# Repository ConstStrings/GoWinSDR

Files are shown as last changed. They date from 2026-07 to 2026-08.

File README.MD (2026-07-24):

# GoWinSDRv2 即将发布，正在开发中

**主要改进及进度如下**

| 名称 | 功能或改进 | 开发进度 |
| --- | --- | --- |
| SDR核心底板 | 优化射频布局，优化以太网布局，增强稳定性；优化接口排布；预留烧录器接口；增加40pin拓展接口；采用温度补偿晶振；添加状态指示灯 | 硬件打板完成，正在调试 |
| 板载烧录器  | 可直接固定在SDR核心底板上，一线烧录 | 开发完成 |
| SDR扩展底板 | 集成DAC模拟输出，音频输出及音频功放，GPS时钟校准，串口屏 | 正在设计PCB |
| FPGA程序 | 修复已知bug | 正在开发 |

**目前v2版本尚未开发完毕，正常情况下请勿使用该版本！！！该页面仅供预览，请使用v1版本！！！**

# GoWinSDR

**最后由ConstString于2026-03-16编辑**

**Click to Read English Version：https://github.com/ConstStrings/GoWinSDR/blob/master/README_EN.MD**

## 工程简介

**本项目基于高云 GW5AT-LV60 FPGA与ADI AD9363/AD9361射频收发器，构建了一套灵活可重构的软件无线电（SDR）系统。通过软硬件协同设计，将高速基带处理部署于FPGA，将交互业务部署于Python上位机，通过千兆以太网交互，实现了QPSK等多种实时通信与动态参数配置**

系统可通过千兆以太网或 USB2.0 (开发中)接口连接 PC 端，配套开发的图形用户界面（GUI上位机）能够直观展示通信参数、数据传输状态等信息，支持用户实时配置系统参数、监控传输过程，大幅提升了人机交互体验。经实际测试，该 SDR 无线通信系统可实现两台设备间的真实无线通信，数据传输速率高达 4Mbps

本工程所使用的FPGA只有PL端，因此将AD936X射频芯片的初始化部分代码移植至STM32平台，经测试运行稳定，使用较为方便。除初始化外的所有逻辑均在FPGA上用Verilog实现

相比Xilinx ZYNQ平台上众多的软件无线电开源项目，本项目没有使用异构FPGA，核心逻辑均使用Verilog实现，数据传输路径更加清晰，操作逻辑更加直观和接近底层，便于无线电爱好者/通信工程师/学生等人群更深入的了解软件无线电基本原理，或作为基本平台进行编码等内容的二次开发



## 工程结构

```

GoWinSDR/
├── FPGA/
│   ├── SDR_Final_CMOS/ # 完整版FPGA项目，基于SDR Base底板，实现所有功能
│   ├── SDR_TANG_CMOS/ # AD9363测试项目，基于AD9363_Debug测试板和Sipeed Tang Mega开发板，只能收发单音信号
│   └── Submodule/ # 用于存放测试时使用的子模块，非开发人员请勿使用
├── Firmware/
│   └── GoWinSDR_STM32/ # 初始化AD9363的STM32代码，移植自Xilinx，使用HAL库开发
├── Hardware/
│   ├── Gerber/ # PCB制版文件
│   ├── ProPrj_AD9363_Debug/ # 嘉立创EDA工程，AD9363功能测试板
│   └── ProPrj_GoWinSDR_SMT/ # 嘉立创EDA工程，项目完整PCB
├── Image/  # 存放文档图片
├── Matlab/  # 用于生成滤波器系数
├── Software/ # 基于PyQt的上位机
└── README.MD
```

## 系统框图



## 快速使用

1. **打样工程ProPrj_GoWinSDR_SMT并焊接，测试各部分电源正常**
2. **打开工程GoWinSDR_STM32，通过板载SWD烧录STM32程序**
3. **打开工程SDR_Final_CMOS，将程序下载/固化到FPGA**
4. **使用Pycharm或其他软件运行上位机，检测参数能否配置，能否收发信号**
5. **若发现某一部分工作异常，可以通过串口和高云FPGA内置逻辑分析仪分析错误**

## 核心代码功能介绍
**核心代码位于目录\FPGA\SDR_Final_CMOS\src下**

### 顶层模块
#### `top.v`
> 顶层模块，负责连接各子模块
---
### AD936X 接口
#### `ad9363_dev_cmos.v`
> AD9363 CMOS接口驱动模块。使用IDDR原语从12位并行总线同时采集I/Q两路ADC数据，使用ODDR原语将I/Q两路DAC数据交替输出至发送总线，实现AD9363芯片的收发时序控制。
---
### 以太网
#### `eth_transceiver.v`
> 以太网收发器顶层模块。通过RGMII接口驱动千兆PHY芯片，内部集成125MHz PLL、UDP/IP协议栈，对外提供简洁的用户数据收发接口，支持ARP应答与UDP数据包的封装解析。
#### `eth_frame_gene.v`
> 射频数据帧封装模块（`rf_data_processor`）。将以太网接收到的用户数据加上自定义帧头（`0xEB90CAD3`）和帧尾（`0x55AA5C4B`），通过跨时钟域FIFO送至射频发送侧，用于无线链路的帧同步。
#### `eth_pack.v`
> 射频数据解帧模块（`rf_data_framer`）。从射频解调比特流中搜索帧头，提取有效载荷，通过跨时钟域FIFO送至以太网发送侧，同时支持IQ互换帧头识别与超时帧错误检测。
#### `arp_responder.v`
> ARP响应模块。监听以太网输入数据流，识别ARP请求包并提取发送方MAC/IP，自动构造并回复ARP应答帧，使PC能够正确解析FPGA的MAC地址。
#### `crc.v`
> CRC校验模块，用于以太网帧数据的完整性校验。
---
### 调制解调
#### `qpsk_demod.v`
> QPSK解调顶层模块。集成采样时钟生成、DDS载波生成、混频下变频、低通滤波、Costas环载波同步、Gardner定时同步及差分解码等子模块，完成从中频采样数据到基带比特流的完整解调链路。
#### `costas.v`
> Costas环载波恢复模块。利用片内DDS生成本地载波，对输入I/Q信号进行正交混频，经鉴相器与环路滤波器闭环控制DDS相位，消除接收信号的载波频偏与相偏。
#### `costas_flt_new.v`
> 改进型Costas环路滤波器（`costas_loop_filter_new`）。实现带积分饱和保护的PI（比例-积分）控制器，可配置KP/KI增益参数，将鉴相器误差转换为DDS相位调整量，加快环路锁定速度并提升稳定性。
#### `costas_loop_filter.v`
> Costas环一阶IIR环路滤波器。实现系统函数 `H(z) = c1 + c2·z⁻¹/(1−z⁻¹)` 的差分方程，采用双增益系数组自适应切换策略（前期大系数快速牵引，后期小系数稳定跟踪），输出24位相位控制字。
#### `phase_detector.v`
> QPSK载波同步鉴相器。依据I/Q两路低通滤波后信号的符号位，采用判决引导法计算相位误差：`error = Q·sign(I) − I·sign(Q)`，输出58位有符号相位误差供环路滤波器使用。
#### `gardner_sync.v`
> Gardner定时同步顶层模块。串联内插滤波器、Gardner TED误差检测器与NCO，构成完整的符号定时恢复闭环，输出最佳抽样时刻的I/Q判决数据及同步标志。
#### `gardner_ted.v`
> Gardner定时误差检测器（TED）。利用Gardner算法 `e(k) = I(k−1)·[I(k)−I(k−2)]` 计算符号定时误差，经一阶IIR环路滤波后输出16位误差控制字，同时在最佳判决时刻输出I/Q硬判决数据。
#### `nco.v`
> 数控振荡器（NCO）模块。接收环路滤波器输出的频率控制字`w(n)`，对内部寄存器η递减累加，当η下溢（出现负值）时产生strobe溢出信号，同时输出用于内插滤波器的小数间隔μk，实现符号定时控制。
#### `interpolate_filter.v`
> Farrow结构内插滤波器。依据NCO输出的小数间隔μk，对I/Q输入样值序列进行分段多项式内插（`y(k) = f1·μk² + f2·μk + f3`），在任意相位点重建信号，实现非整数倍采样率转换。
---
### 射频收发
#### `rf_rxt.v`
> 射频收发处理顶层模块。接收侧串联Costas环、Gardner定时同步与差分解码，完成QPSK解调输出比特流；发送侧对输入字节数据进行差分编码与QPSK星座映射，驱动DAC输出I/Q基带信号。
#### `rf_diff_encode.v`
> QPSK差分编码模块（`qpsk_differential_encoder`）。将当前2位输入数据与上一时刻I/Q状态进行异或运算，实现差分相移编码（DQPSK），消除解调端的相位模糊问题。
#### `rf_diff_decode.v`
> QPSK差分解码模块（`qpsk_differential_decoder`）。将当前I/Q判决位与前一符号进行异或，恢复原始2位数据，与差分编码端对应，实现相位模糊的透明消除。
---
### 其他
#### `calibration.v`
> 信号校准模块。对ADC输入数据进行平方运算，经FIR低通滤波提取信号包络，再由正弦波频率计测量当前频率，最终通过`data_sender_24bit`将24位校准频率数据输出至外部（STM32），用于系统标定。
#### `com_fpga.v`
> FPGA与MCU通信模块（`data_sender_24bit`）。将128分频后的低速时钟作为数据时钟，在STM32请求信号触发下，按状态机逐字节串行输出24位数据，实现FPGA向STM32的同步并行数据传输。
#### `led_control.v`
> 433MHz OOK解调模块（`demod_433`）。对ADC输入的I/Q信号计算瞬时功率（I²+Q²），经64次滑动平均滤波后与功率阈值比较，输出OOK解调数据位，可用于LED状态指示或低速遥控信号接收。
---
### 约束文件
#### `SDR_Test.cst`
> 管脚约束文件
#### `timeconstrain.sdc`
> 时序约束文件
#### `SDR_Test.rao`
> 逻辑分析仪配置文件

## ARM端程序使用方法

**核心代码位于目录\Firmware\GoWinSDR_STM32\Hardware下**

主程序已经实现串口命令读取和配置参数，故可以不用修改代码，直接烧录。需要根据实际引脚修改文件`\Firmware\GoWinSDR_STM32\\Hardware\api\softspi.h`内的SPI相关引脚。

如果想进行更加细致的配置，可修改main.c内的初始化结构体 `AD9361_InitParam default_init_param`，参数具体含义已在注释中

初始化时会通过串口打印初始化日志，初始化成功后打印当前状态：

```
采样频率:
  RX: 61440000 Hz (61.44 MSPS)
  TX: 61440000 Hz (61.44 MSPS)
ad9361_rfpll_int_recalc_rate: Parent Rate 80000000 Hz
ad9361_rfpll_int_recalc_rate: Parent Rate 80000000 Hz

LO频率:
  RX: 2400000000 Hz (2.400 GHz)
  TX: 2400000000 Hz (2.400 GHz)
ad9361_set_tx_atten : attenuation 0 mdB tx1=1 tx2=0
Rx gain can be set in MGC mode only
ad9361_rf_port_setup : INPUT_SELECT 0x3

=== Final Status ===
ENSM (0x017): 0x1A (TX_ON=1)
TX Ctrl (0x002): 0x58
PLL Lock (0x247): 0x02 (TX_PLL=1)
```

支持使用的命令如下，使用串口即可配置，想要查看和修改指令逻辑可以查看\Firmware\GoWinSDR_STM32\\Hardware\ad9361\command.c：

```
help?  - Displays all available commands.
register?  - Gets the specified register value.
tx_lo_freq?  - Gets current TX LO frequency [MHz].
tx_lo_freq=  - Sets the TX LO frequency [MHz].
tx_samp_freq?  - Gets current TX sampling frequency [Hz].
tx_samp_freq=  - Sets the TX sampling frequency [Hz].
tx_rf_bandwidth?  - Gets current TX RF bandwidth [Hz].
tx_rf_bandwidth=  - Sets the TX RF bandwidth [Hz].
tx1_attenuation?  - Gets current TX1 attenuation [mdB].
tx1_attenuation=  - Sets the TX1 attenuation [mdB].
tx2_attenuation?  - Gets current TX2 attenuation [mdB].
tx2_attenuation=  - Sets the TX2 attenuation [mdB].
tx_fir_en?  - Gets current TX FIR state.
tx_fir_en=  - Sets the TX FIR state.
rx_lo_freq?  - Gets current RX LO frequency [MHz].
rx_lo_freq=  - Sets the RX LO frequency [MHz].
rx_samp_freq?  - Gets current RX sampling frequency [Hz].
rx_samp_freq=  - Sets the RX sampling frequency [Hz].
rx_rf_bandwidth?  - Gets current RX RF bandwidth [Hz].
rx_rf_bandwidth=  - Sets the RX RF bandwidth [Hz].
rx1_gc_mode?  - Gets current RX1 GC mode.
rx1_gc_mode=  - Sets the RX1 GC mode.
rx2_gc_mode?  - Gets current RX2 GC mode.
rx2_gc_mode=  - Sets the RX2 GC mode.
rx1_rf_gain?  - Gets current RX1 RF gain.
rx1_rf_gain=  - Sets the RX1 RF gain.
rx2_rf_gain?  - Gets current RX2 RF gain.
rx2_rf_gain=  - Sets the RX2 RF gain.
rx_fir_en?  - Gets current RX FIR state.
rx_fir_en=  - Sets the RX FIR state.
dds_tx1_tone1_freq?  - Gets current DDS TX1 Tone 1 frequency [Hz].
dds_tx1_tone1_freq=  - Sets the DDS TX1 Tone 1 frequency [Hz].
dds_tx1_tone2_freq?  - Gets current DDS TX1 Tone 2 frequency [Hz].
dds_tx1_tone2_freq=  - Sets the DDS TX1 Tone 2 frequency [Hz].
dds_tx1_tone1_phase?  - Gets current DDS TX1 Tone 1 phase [degrees].
dds_tx1_tone1_phase=  - Sets the DDS TX1 Tone 1 phase [degrees].
dds_tx1_tone2_phase?  - Gets current DDS TX1 Tone 2 phase [degrees].
dds_tx1_tone2_phase=  - Sets the DDS TX1 Tone 2 phase [degrees].
dds_tx1_tone1_scale?  - Gets current DDS TX1 Tone 1 scale.
dds_tx1_tone1_scale=  - Sets the DDS TX1 Tone 1 scale.
dds_tx1_tone2_scale?  - Gets current DDS TX1 Tone 2 scale.
dds_tx1_tone2_scale=  - Sets the DDS TX1 Tone 2 scale.
dds_tx2_tone1_freq?  - Gets current DDS TX2 Tone 1 frequency [Hz].
dds_tx2_tone1_freq=  - Sets the DDS TX2 Tone 1 frequency [Hz].
dds_tx2_tone2_freq?  - Gets current DDS TX2 Tone 2 frequency [Hz].
dds_tx2_tone2_freq=  - Sets the DDS TX2 Tone 2 frequency [Hz].
dds_tx2_tone1_phase?  - Gets current DDS TX2 Tone 1 phase [degrees].
dds_tx2_tone1_phase=  - Sets the DDS TX2 Tone 1 phase [degrees].
dds_tx2_tone2_phase?  - Gets current DDS TX2 Tone 2 phase [degrees].
dds_tx2_tone2_phase=  - Sets the DDS TX2 Tone 2 phase [degrees].
dds_tx2_tone1_scale?  - Gets current DDS TX2 Tone 1 scale.
dds_tx2_tone1_scale=  - Sets the DDS TX2 Tone 1 scale.
dds_tx2_tone2_scale?  - Gets current DDS TX2 Tone 2 scale.
dds_tx2_tone2_scale=  - Sets the DDS TX2 Tone 2 scale.
calibration?  - Get Lo Freq diff.
calibration=  - Calibrate Lo Freq diff.
rx_lo_up=  - Increase RX LO frequency.
rx_lo_down=  - Decrease RX LO frequency.
query_led_state?  - Decrease RX LO frequency.
query_led_state=  - Decrease RX LO frequency.

```

## 上位机功能介绍

上位机基于 **Python + PyQt6** 开发，采用多线程架构，通过串口与以太网双通道与 FPGA 通信，提供图形化的参数配置、数据收发与实时监控功能。

---

### 启动方法

安装好Python开发环境后，在PyCharm等软件内运行main.py

### 整体架构

主窗口 (`main_window.py`) 采用左右分栏布局：左侧为配置区，右侧为多选项卡功能区。后台运行多个独立的 QThread 工作线程，分别负责串口通信、UDP 网络收发、音频流采集/播放和摄像头采集，所有线程间通过 Qt 信号槽机制进行线程安全的数据传递。

---

### 串口通信

`serial_worker.py` 实现了串口工作线程，支持可用端口枚举、可配置波特率（最高 921600bps）的串口连接/断开，以及全双工的数据收发。接收端对数据流进行逐行解析：格式为 `key=value` 的响应被识别为参数回调并转发至参数面板，其余内容作为日志显示。

`config_widget.py` 提供串口配置 UI，包含端口刷新、波特率选择及连接状态管理。

---

### 以太网通信（UDP）

`ethernet_worker.py` 实现了基于 UDP 的可靠/不可靠双模式传输协议：

- **文本命令**：采用停等协议（Stop-and-Wait），支持最多 128 次重传。
- **文件传输**：先用停等协议发送文件头（含文件名与大小），再用 **SR（Selective Repeat）滑动窗口协议**（窗口大小为 4）发送文件数据，实现乱序重传；全程携带 CRC32 校验。
- **实时视频流**：采用自定义分包协议（帧头含帧ID、分片序号、总分片数），允许丢包，每帧拆分为最大 1024 字节的分片后以不可靠方式发送，接收端按帧ID进行分片重组。
- **实时音频流**：以不可靠方式直接发送 PCM 音频块，保证低延迟实时性。

`ethernet_widget.py` 提供 UDP 配置 UI，含 FPGA 目标地址（IP/端口）和本地监听地址配置，以及开始/停止监听按钮。

---

### AD9363 参数配置

`params_widget.py` 提供 AD9363 射频芯片的参数配置面板，分 TX（发射）和 RX（接收）两个选项卡，涵盖本振频率、采样率、射频带宽、增益控制、FIR 使能及 DDS 音调频率等参数的读取与设置。每个参数条目包含输入框和 Set 按钮，点击后通过串口发送 `key=value` 格式命令。支持"手动查询所有参数"一键刷新，以及在连接后自动批量查询所有 GET 命令（`ad9363_config.py` 中定义）。

---

### 文件、文本及录音

`text_audio_widget.py` 支持通过串口发送文本消息，以及触发音频录制/停止。

`file_send_widget.py` 实现文件发送 UI，包含文件浏览、文件信息预览（文件名、大小、类型、路径），以及带实时进度条、传输速率（Mbps）和预计剩余时间的传输状态显示。

`file_receive_widget.py` 实现文件接收 UI，支持启用/禁用文件接收，显示带进度条和速率的实时接收状态，已接收文件列入表格并可选择保存到本地。

---

### 实时语音传输

`realtime_audio_widget.py` 提供实时双向语音传输界面，发射侧支持枚举系统音频输入设备（包括 WASAPI 内录），选择音源后启动麦克风采集并通过 UDP 实时发送；接收侧将网络接收的 PCM 数据送入音频输出队列实时播放。两侧均内嵌波形图实时显示音频波形。

`audio_stream_worker.py` 基于 sounddevice 库实现：`AudioInputWorker` 以回调方式从指定设备连续采集 44100Hz/单声道/float32 音频块；`AudioOutputWorker` 通过队列缓冲驱动扬声器输出，缓冲不足时静音以减少噪声。

---

### 实时视频传输

`realtime_video_widget.py` 提供实时双向视频界面，发射侧开启本地摄像头并实时预览，同时将视频帧编码为 WebP 格式通过 UDP 发送；接收侧将网络视频帧解码后实时渲染。

`camera_worker.py` 基于 OpenCV 实现摄像头采集，在独立内部线程中以设定的限速循环抓帧，水平翻转后分别发出 QImage（供本地预览）和 WebP 字节流（供网络发送）两路信号。

---

### 网络视频监控

`video_widget.py` 提供独立的 UDP 视频监控选项卡，仅用于接收和显示来自 FPGA/网络的视频流，支持视频标签自动缩放。

---

### 无线物联网控制

`iot_widget.py` 实现一个简单的 IoT 设备状态监控演示页面。启动监控后自动设置 RX 本振频率至 434MHz，并以 500ms 为周期轮询 `query_led_state?` 指令；根据串口返回的状态（"1"/"0"）驱动自绘灯泡控件亮起或熄灭，模拟 433MHz 无线遥控设备的状态可视化。

---

### 波形显示

`waveform_widget.py` 是一个基于 QPainter 和 NumPy 的自定义音频波形控件，采用离屏 Pixmap 双缓冲渲染，支持可调增益放大（默认 5 倍）与幅度裁剪，自适应控件宽度对波形数据进行采样/插值显示。

---

## PCB相关事项（重要，仔细阅读）

1. 由于包含射频和高速信号，进行PCB打样时**需要进行阻抗管控**！！！，使用嘉立创进行打样，层压选择**JLC06161H-3313**，阻抗管控+/-20%即可

2. 焊接时如果没有把握，**请务必先焊接电源部分，确定电源输出电压正常后再焊接其他部分**，防止烧毁芯片

3. 上电前请**确定各路电源是否对地短路**，即使是SMT也是有可能短路的

4. PCB已经经过多版本迭代，理论上不存在重大问题，请先确定焊接是否到位

5. **重要！！：核心板上可以通过VDDIO设置bank电压，但如果和底板同时提供VDDIO会造成冲突，因此需要在插入核心板前将核心板上的IO供电移除，具体方法如下**

   查看核心板原理图，发现VDDIO供电经过磁珠连接到3.3v电源，我们只需要断开我们所使用Bank对应的磁珠，**FB14,FB15,FB16**

   

	这三个磁珠在核心板背面对应的位置如下，需要用烙铁将这三个磁珠去除即可

        

## 测试结果

### 文件传输测试



### 逻辑分析仪（截图时QPSK正在修复问题，暂时采用BPSK）

#### 完整系统时序图



#### AD9363单独测试

测试在2.4GHz频段下进行BPSK通信，最上面的四行分别是接收IQ路和发射IQ路，波形较为完整，没有明显的失真





测试在2.4GHz情况下，**不插天线**，观察正弦单音信号的失真情况



### 上位机视频传输

使用上位机的视频传输功能，可以使用在参数设置页面自定义的频段传输实时视频流。使用自收自发的方式（可以板间传输）进行测试，视频源为笔记本摄像头，左侧画面为摄像头捕获画面，右侧为从射频信号中解码所得的画面。得益于FPGA的强实时性，几乎感受不到延迟



### 以太网数据流

通过WireShark软件可以查看在以太网中传输的数据流，传输文件过程中的以太网数据流如下，分为数据帧和ACK帧



### 频谱情况（早期测试结果）



## 成品展示









## 声明

- 本工程的Costas环与Gardner环部分参考开源工程：https://github.com/lauchinyuan/FPGA_QPSK-modem 非常感谢大佬的开源
- 本工程的以太网收发器部分参考自Sipeed例程：https://github.com/sipeed/TangMega-138K-example，本工程初始验证版也是基于Sipeed出品的TangMega-138K开发板

## 写在最后

**这个工程耗费我个人及我们团队相当大的精力，尽管AD936X是一款资料较多的成熟芯片，但现有项目基本是建立在ZYNQ系列上的，代码耦合程度较高，不方便学习。调试软件和硬件的过程非常痛苦，但好在最后成功将整个系统基本搭建成功，并在2025年的嵌赛FPGA赛道决赛中获得奖项。由于各种各样的主客观原因，一部分设计目标尚未完成，ARP请求未实现需手动添加（截止2026-3-10），QPSK会出现bug（截止2026-3-10）,  Gardner环在高码率会失锁（截止2026-3-10），在繁忙的学业之余，我会尽力去完善这个项目，也希望大家谅解**

如果有任何问题或想要交流，可以通过邮件联系我：
3207235590@qq.com
conststrings@gmail.com

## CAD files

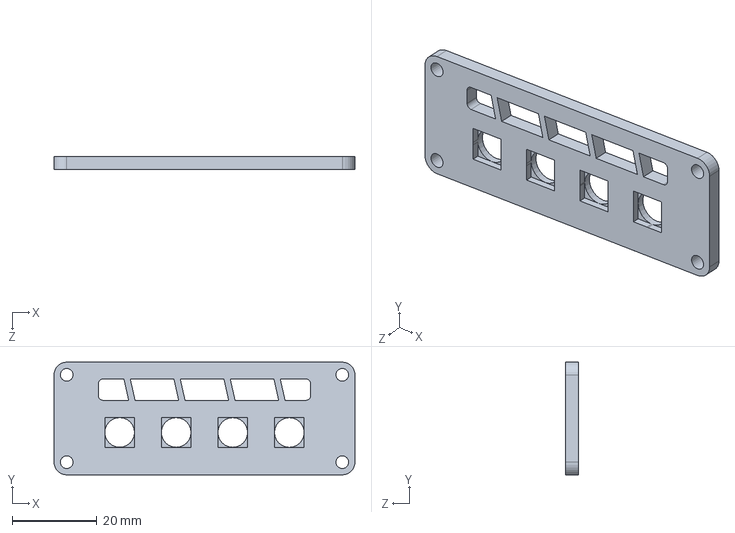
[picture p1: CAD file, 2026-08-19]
Struct/left.SLDPRT
71.0 x 26.6 x 3.00 mm

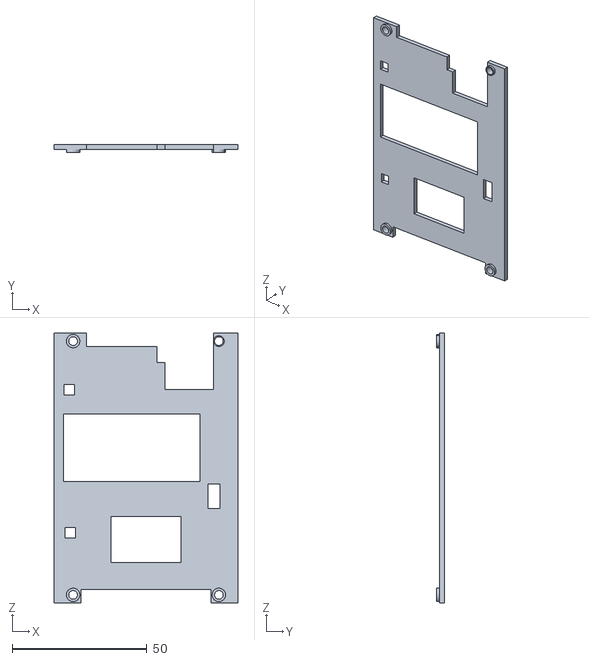
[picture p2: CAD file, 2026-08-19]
Struct/base3.STL
68.0 x 2.80 x 100.0

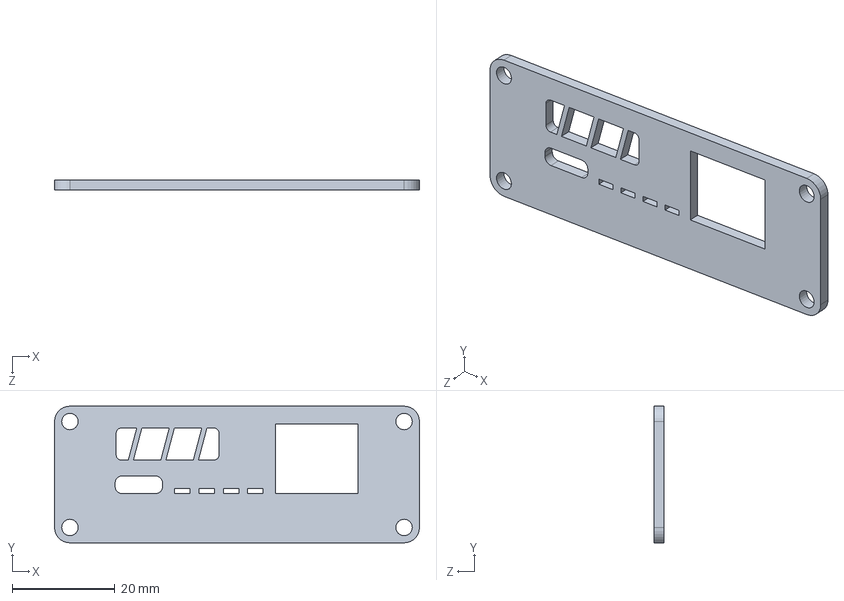
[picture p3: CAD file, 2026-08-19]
Struct/right.SLDPRT
71.0 x 26.6 x 2.00 mm

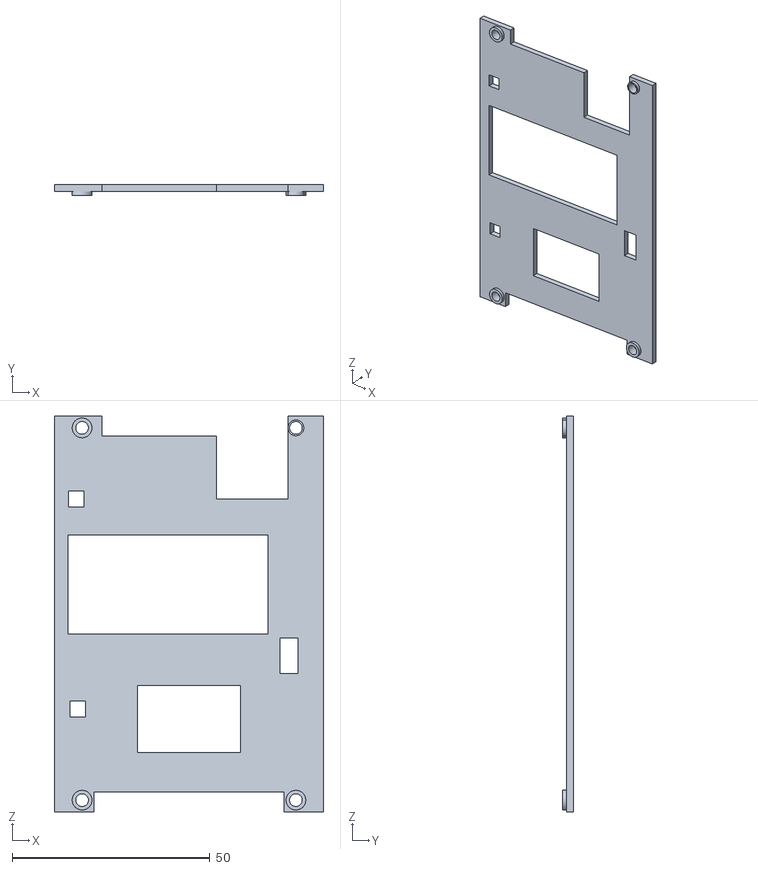
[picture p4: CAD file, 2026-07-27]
Struct/base2.STL
68.0 x 2.80 x 100.0

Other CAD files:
Struct/base.SLDPRT
Struct/base.STL
Struct/left.STL
Struct/right.STL

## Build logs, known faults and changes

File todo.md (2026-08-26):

1. 查看原始波形质量（正弦收发）
2. costas有问题
3. 信道编码
4. 连续数据流控，DDR buffer

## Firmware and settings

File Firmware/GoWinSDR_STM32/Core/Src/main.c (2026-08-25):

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
/* Includes ------------------------------------------------------------------*/
#include "main.h"
#include "adc.h"
#include "spi.h"
#include "tim.h"
#include "usart.h"
#include "gpio.h"

/* USER CODE BEGIN Includes */
#include "com_debug.h"
#include "config.h"
#include "ad9361_api.h"
#include "parameters.h"
#include "platform.h"
#include "command.h"
#include "console.h"
#include "adc_core.h"
#include "dac_core.h"
#include "softspi.h"
/* USER CODE END Includes */


void SystemClock_Config(void);
/* USER CODE BEGIN 0 */
#ifdef CONSOLE_COMMANDS
extern command	  	cmd_list[];
extern char			cmd_no;
extern cmd_function	cmd_functions[11];
unsigned char		cmd				 =  0;
double				param[5]		 = {0, 0, 0, 0, 0};
char				param_no		 =  0;
int					cmd_type		 = -1;
char				invalid_cmd		 =  0;
char				received_cmd[30] = {0, 0, 0, 0, 0, 0, 0, 0, 0, 0,
										0, 0, 0, 0, 0, 0, 0, 0, 0, 0,
										0, 0, 0, 0, 0, 0, 0, 0, 0, 0};
#endif

AD9361_InitParam default_init_param = {
	/* Device selection */
	ID_AD9361,	// dev_sel
	/* Identification number */
	0,		//id_no
	/* Reference Clock */
	40000000UL,	//reference_clk_rate
	/* Base Configuration */
	0,		//two_rx_two_tx_mode_enable *** adi,2rx-2tx-mode-enable
	1,		//one_rx_one_tx_mode_use_rx_num *** adi,1rx-1tx-mode-use-rx-num
	1,		//one_rx_one_tx_mode_use_tx_num *** adi,1rx-1tx-mode-use-tx-num
	1,		//frequency_division_duplex_mode_enable *** adi,frequency-division-duplex-mode-enable
	0,		//frequency_division_duplex_independent_mode_enable *** adi,frequency-division-duplex-independent-mode-enable
	0,		//tdd_use_dual_synth_mode_enable *** adi,tdd-use-dual-synth-mode-enable
	0,		//tdd_skip_vco_cal_enable *** adi,tdd-skip-vco-cal-enable
	0,		//tx_fastlock_delay_ns *** adi,tx-fastlock-delay-ns
	0,		//rx_fastlock_delay_ns *** adi,rx-fastlock-delay-ns
	0,		//rx_fastlock_pincontrol_enable *** adi,rx-fastlock-pincontrol-enable
	0,		//tx_fastlock_pincontrol_enable *** adi,tx-fastlock-pincontrol-enable
	0,		//external_rx_lo_enable *** adi,external-rx-lo-enable
	0,		//external_tx_lo_enable *** adi,external-tx-lo-enable
	5,		//dc_offset_tracking_update_event_mask *** adi,dc-offset-tracking-update-event-mask
	6,		//dc_offset_attenuation_high_range *** adi,dc-offset-attenuation-high-range
	5,		//dc_offset_attenuation_low_range *** adi,dc-offset-attenuation-low-range
	0x28,	//dc_offset_count_high_range *** adi,dc-offset-count-high-range
	0x32,	//dc_offset_count_low_range *** adi,dc-offset-count-low-range
	0,		//split_gain_table_mode_enable *** adi,split-gain-table-mode-enable
	MAX_SYNTH_FREF,	//trx_synthesizer_target_fref_overwrite_hz *** adi,trx-synthesizer-target-fref-overwrite-hz
	0,		// qec_tracking_slow_mode_enable *** adi,qec-tracking-slow-mode-enable
	/* ENSM Control */
	0,		//ensm_enable_pin_pulse_mode_enable *** adi,ensm-enable-pin-pulse-mode-enable
	0,		//ensm_enable_txnrx_control_enable *** adi,ensm-enable-txnrx-control-enable
	/* LO Control */
	2400000000UL,	//rx_synthesizer_frequency_hz *** adi,rx-synthesizer-frequency-hz
	2400000000UL,	//tx_synthesizer_frequency_hz *** adi,tx-synthesizer-frequency-hz
	/* Rate & BW Control */
	{983040000, 245760000, 122880000, 61440000, 30720000, 30720000},//uint32_t	rx_path_clock_frequencies[6] *** adi,rx-path-clock-frequencies
	{983040000, 245760000, 122880000, 61440000, 30720000, 30720000},//uint32_t	tx_path_clock_frequencies[6] *** adi,tx-path-clock-frequencies
	18000000,//rf_rx_bandwidth_hz *** adi,rf-rx-bandwidth-hz
	18000000,//rf_tx_bandwidth_hz *** adi,rf-tx-bandwidth-hz
	/* RF Port Control */
	0,		//rx_rf_port_input_select *** adi,rx-rf-port-input-select
	0,		//tx_rf_port_input_select *** adi,tx-rf-port-input-select
	/* TX Attenuation Control */
	0,	//tx_attenuation_mdB *** adi,tx-attenuation-mdB
	0,		//update_tx_gain_in_alert_enable *** adi,update-tx-gain-in-alert-enable
	/* Reference Clock Control */
	0,		//xo_disable_use_ext_refclk_enable *** adi,xo-disable-use-ext-refclk-enable
	{8, 5920},	//dcxo_coarse_and_fine_tune[2] *** adi,dcxo-coarse-and-fine-tune
	CLKOUT_DISABLE,	//clk_output_mode_select *** adi,clk-output-mode-select
	/* Gain Control */
	RF_GAIN_SLOWATTACK_AGC,		//gc_rx1_mode *** adi,gc-rx1-mode
	RF_GAIN_SLOWATTACK_AGC,		//gc_rx2_mode *** adi,gc-rx2-mode
	58,		//gc_adc_large_overload_thresh *** adi,gc-adc-large-overload-thresh
	4,		//gc_adc_ovr_sample_size *** adi,gc-adc-ovr-sample-size
	47,		//gc_adc_small_overload_thresh *** adi,gc-adc-small-overload-thresh
	8192,	//gc_dec_pow_measurement_duration *** adi,gc-dec-pow-measurement-duration
	0,		//gc_dig_gain_enable *** adi,gc-dig-gain-enable
	800,	//gc_lmt_overload_high_thresh *** adi,gc-lmt-overload-high-thresh
	704,	//gc_lmt_overload_low_thresh *** adi,gc-lmt-overload-low-thresh
	24,		//gc_low_power_thresh *** adi,gc-low-power-thresh
	15,		//gc_max_dig_gain *** adi,gc-max-dig-gain
	/* Gain MGC Control */
	2,		//mgc_dec_gain_step *** adi,mgc-dec-gain-step
	2,		//mgc_inc_gain_step *** adi,mgc-inc-gain-step
	0,		//mgc_rx1_ctrl_inp_enable *** adi,mgc-rx1-ctrl-inp-enable
	0,		//mgc_rx2_ctrl_inp_enable *** adi,mgc-rx2-ctrl-inp-enable
	0,		//mgc_split_table_ctrl_inp_gain_mode *** adi,mgc-split-table-ctrl-inp-gain-mode
	/* Gain AGC Control */
	10,		//agc_adc_large_overload_exceed_counter *** adi,agc-adc-large-overload-exceed-counter
	2,		//agc_adc_large_overload_inc_steps *** adi,agc-adc-large-overload-inc-steps
	0,		//agc_adc_lmt_small_overload_prevent_gain_inc_enable *** adi,agc-adc-lmt-small-overload-prevent-gain-inc-enable
	10,		//agc_adc_small_overload_exceed_counter *** adi,agc-adc-small-overload-exceed-counter
	4,		//agc_dig_gain_step_size *** adi,agc-dig-gain-step-size
	3,		//agc_dig_saturation_exceed_counter *** adi,agc-dig-saturation-exceed-counter
	1000,	// agc_gain_update_interval_us *** adi,agc-gain-update-interval-us
	0,		//agc_immed_gain_change_if_large_adc_overload_enable *** adi,agc-immed-gain-change-if-large-adc-overload-enable
	0,		//agc_immed_gain_change_if_large_lmt_overload_enable *** adi,agc-immed-gain-change-if-large-lmt-overload-enable
	10,		//agc_inner_thresh_high *** adi,agc-inner-thresh-high
	1,		//agc_inner_thresh_high_dec_steps *** adi,agc-inner-thresh-high-dec-steps
	12,		//agc_inner_thresh_low *** adi,agc-inner-thresh-low
	1,		//agc_inner_thresh_low_inc_steps *** adi,agc-inner-thresh-low-inc-steps
	10,		//agc_lmt_overload_large_exceed_counter *** adi,agc-lmt-overload-large-exceed-counter
	2,		//agc_lmt_overload_large_inc_steps *** adi,agc-lmt-overload-large-inc-steps
	10,		//agc_lmt_overload_small_exceed_counter *** adi,agc-lmt-overload-small-exceed-counter
	5,		//agc_outer_thresh_high *** adi,agc-outer-thresh-high
	2,		//agc_outer_thresh_high_dec_steps *** adi,agc-outer-thresh-high-dec-steps
	18,		//agc_outer_thresh_low *** adi,agc-outer-thresh-low
	2,		//agc_outer_thresh_low_inc_steps *** adi,agc-outer-thresh-low-inc-steps
	1,		//agc_attack_delay_extra_margin_us; *** adi,agc-attack-delay-extra-margin-us
	0,		//agc_sync_for_gain_counter_enable *** adi,agc-sync-for-gain-counter-enable
	/* Fast AGC */
	64,		//fagc_dec_pow_measuremnt_duration ***  adi,fagc-dec-pow-measurement-duration
	260,	//fagc_state_wait_time_ns ***  adi,fagc-state-wait-time-ns
	/* Fast AGC - Low Power */
	0,		//fagc_allow_agc_gain_increase ***  adi,fagc-allow-agc-gain-increase-enable
	5,		//fagc_lp_thresh_increment_time ***  adi,fagc-lp-thresh-increment-time
	1,		//fagc_lp_thresh_increment_steps ***  adi,fagc-lp-thresh-increment-steps
	/* Fast AGC - Lock Level */
	10,		//fagc_lock_level ***  adi,fagc-lock-level
	1,		//fagc_lock_level_lmt_gain_increase_en ***  adi,fagc-lock-level-lmt-gain-increase-enable
	5,		//fagc_lock_level_gain_increase_upper_limit ***  adi,fagc-lock-level-gain-increase-upper-limit
	/* Fast AGC - Peak Detectors and Final Settling */
	1,		//fagc_lpf_final_settling_steps ***  adi,fagc-lpf-final-settling-steps
	1,		//fagc_lmt_final_settling_steps ***  adi,fagc-lmt-final-settling-steps
	3,		//fagc_final_overrange_count ***  adi,fagc-final-overrange-count
	/* Fast AGC - Final Power Test */
	0,		//fagc_gain_increase_after_gain_lock_en ***  adi,fagc-gain-increase-after-gain-lock-enable
	/* Fast AGC - Unlocking the Gain */
	0,		//fagc_gain_index_type_after_exit_rx_mode ***  adi,fagc-gain-index-type-after-exit-rx-mode
	1,		//fagc_use_last_lock_level_for_set_gain_en ***  adi,fagc-use-last-lock-level-for-set-gain-enable
	1,		//fagc_rst_gla_stronger_sig_thresh_exceeded_en ***  adi,fagc-rst-gla-stronger-sig-thresh-exceeded-enable
	5,		//fagc_optimized_gain_offset ***  adi,fagc-optimized-gain-offset
	10,		//fagc_rst_gla_stronger_sig_thresh_above_ll ***  adi,fagc-rst-gla-stronger-sig-thresh-above-ll
	1,		//fagc_rst_gla_engergy_lost_sig_thresh_exceeded_en ***  adi,fagc-rst-gla-engergy-lost-sig-thresh-exceeded-enable
	1,		//fagc_rst_gla_engergy_lost_goto_optim_gain_en ***  adi,fagc-rst-gla-engergy-lost-goto-optim-gain-enable
	10,		//fagc_rst_gla_engergy_lost_sig_thresh_below_ll ***  adi,fagc-rst-gla-engergy-lost-sig-thresh-below-ll
	8,		//fagc_energy_lost_stronger_sig_gain_lock_exit_cnt ***  adi,fagc-energy-lost-stronger-sig-gain-lock-exit-cnt
	1,		//fagc_rst_gla_large_adc_overload_en ***  adi,fagc-rst-gla-large-adc-overload-enable
	1,		//fagc_rst_gla_large_lmt_overload_en ***  adi,fagc-rst-gla-large-lmt-overload-enable
	0,		//fagc_rst_gla_en_agc_pulled_high_en ***  adi,fagc-rst-gla-en-agc-pulled-high-enable
	0,		//fagc_rst_gla_if_en_agc_pulled_high_mode ***  adi,fagc-rst-gla-if-en-agc-pulled-high-mode
	64,		//fagc_power_measurement_duration_in_state5 ***  adi,fagc-power-measurement-duration-in-state5
	/* RSSI Control */
	1,		//rssi_delay *** adi,rssi-delay
	1000,	//rssi_duration *** adi,rssi-duration
	3,		//rssi_restart_mode *** adi,rssi-restart-mode
	0,		//rssi_unit_is_rx_samples_enable *** adi,rssi-unit-is-rx-samples-enable
	1,		//rssi_wait *** adi,rssi-wait
	/* Aux ADC Control */
	256,	//aux_adc_decimation *** adi,aux-adc-decimation
	40000000UL,	//aux_adc_rate *** adi,aux-adc-rate
	/* AuxDAC Control */
	1,		//aux_dac_manual_mode_enable ***  adi,aux-dac-manual-mode-enable
	0,		//aux_dac1_default_value_mV ***  adi,aux-dac1-default-value-mV
	0,		//aux_dac1_active_in_rx_enable ***  adi,aux-dac1-active-in-rx-enable
	0,		//aux_dac1_active_in_tx_enable ***  adi,aux-dac1-active-in-tx-enable
	0,		//aux_dac1_active_in_alert_enable ***  adi,aux-dac1-active-in-alert-enable
	0,		//aux_dac1_rx_delay_us ***  adi,aux-dac1-rx-delay-us
	0,		//aux_dac1_tx_delay_us ***  adi,aux-dac1-tx-delay-us
	0,		//aux_dac2_default_value_mV ***  adi,aux-dac2-default-value-mV
	0,		//aux_dac2_active_in_rx_enable ***  adi,aux-dac2-active-in-rx-enable
	0,		//aux_dac2_active_in_tx_enable ***  adi,aux-dac2-active-in-tx-enable
	0,		//aux_dac2_active_in_alert_enable ***  adi,aux-dac2-active-in-alert-enable
	0,		//aux_dac2_rx_delay_us ***  adi,aux-dac2-rx-delay-us
	0,		//aux_dac2_tx_delay_us ***  adi,aux-dac2-tx-delay-us
	/* Temperature Sensor Control */
	256,	//temp_sense_decimation *** adi,temp-sense-decimation
	1000,	//temp_sense_measurement_interval_ms *** adi,temp-sense-measurement-interval-ms
	0xCE,	//temp_sense_offset_signed *** adi,temp-sense-offset-signed
	1,		//temp_sense_periodic_measurement_enable *** adi,temp-sense-periodic-measurement-enable
	/* Control Out Setup */
	0xFF,	//ctrl_outs_enable_mask *** adi,ctrl-outs-enable-mask
	0,		//ctrl_outs_index *** adi,ctrl-outs-index
	/* External LNA Control */
	0,		//elna_settling_delay_ns *** adi,elna-settling-delay-ns
	0,		//elna_gain_mdB *** adi,elna-gain-mdB
	0,		//elna_bypass_loss_mdB *** adi,elna-bypass-loss-mdB
	0,		//elna_rx1_gpo0_control_enable *** adi,elna-rx1-gpo0-control-enable
	0,		//elna_rx2_gpo1_control_enable *** adi,elna-rx2-gpo1-control-enable
	0,		//elna_gaintable_all_index_enable *** adi,elna-gaintable-all-index-enable
	/* Digital Interface Control */
	0,		//digital_interface_tune_skip_mode *** adi,digital-interface-tune-skip-mode
	0,		//digital_interface_tune_fir_disable *** adi,digital-interface-tune-fir-disable
	1,		//pp_tx_swap_enable *** adi,pp-tx-swap-enable
	1,		//pp_rx_swap_enable *** adi,pp-rx-swap-enable
	0,		//tx_channel_swap_enable *** adi,tx-channel-swap-enable
	0,		//rx_channel_swap_enable *** adi,rx-channel-swap-enable
	1,		//rx_frame_pulse_mode_enable *** adi,rx-frame-pulse-mode-enable
	0,		//two_t_two_r_timing_enable *** adi,2t2r-timing-enable
	0,		//invert_data_bus_enable *** adi,invert-data-bus-enable
	0,		//invert_data_clk_enable *** adi,invert-data-clk-enable
	0,		//fdd_alt_word_order_enable *** adi,fdd-alt-word-order-enable
	0,		//invert_rx_frame_enable *** adi,invert-rx-frame-enable
	0,		//fdd_rx_rate_2tx_enable *** adi,fdd-rx-rate-2tx-enable
	1,		//swap_ports_enable *** adi,swap-ports-enable
	0,		//single_data_rate_enable *** adi,single-data-rate-enable
	0,		//lvds_mode_enable *** adi,lvds-mode-enable
	0,		//half_duplex_mode_enable *** adi,half-duplex-mode-enable
	0,		//single_port_mode_enable *** adi,single-port-mode-enable
	1,		//full_port_enable *** adi,full-port-enable
	0,		//full_duplex_swap_bits_enable *** adi,full-duplex-swap-bits-enable
	0,		//delay_rx_data *** adi,delay-rx-data
	15,		//rx_data_clock_delay *** adi,rx-data-clock-delay
	0,		//rx_data_delay *** adi,rx-data-delay
	7,		//tx_fb_clock_delay *** adi,tx-fb-clock-delay
	0,		//tx_data_delay *** adi,tx-data-delay
	150,	//lvds_bias_mV *** adi,lvds-bias-mV
	1,		//lvds_rx_onchip_termination_enable *** adi,lvds-rx-onchip-termination-enable 
	0,		//rx1rx2_phase_inversion_en *** adi,rx1-rx2-phase-inversion-enable
	0xFF,	//lvds_invert1_control *** adi,lvds-invert1-control
	0x0F,	//lvds_invert2_control *** adi,lvds-invert2-control
	/* GPO Control */
	0,		//gpo0_inactive_state_high_enable *** adi,gpo0-inactive-state-high-enable
	0,		//gpo1_inactive_state_high_enable *** adi,gpo1-inactive-state-high-enable
	0,		//gpo2_inactive_state_high_enable *** adi,gpo2-inactive-state-high-enable
	0,		//gpo3_inactive_state_high_enable *** adi,gpo3-inactive-state-high-enable
	0,		//gpo0_slave_rx_enable *** adi,gpo0-slave-rx-enable
	0,		//gpo0_slave_tx_enable *** adi,gpo0-slave-tx-enable
	0,		//gpo1_slave_rx_enable *** adi,gpo1-slave-rx-enable
	0,		//gpo1_slave_tx_enable *** adi,gpo1-slave-tx-enable
	0,		//gpo2_slave_rx_enable *** adi,gpo2-slave-rx-enable
	0,		//gpo2_slave_tx_enable *** adi,gpo2-slave-tx-enable
	0,		//gpo3_slave_rx_enable *** adi,gpo3-slave-rx-enable
	0,		//gpo3_slave_tx_enable *** adi,gpo3-slave-tx-enable
	0,		//gpo0_rx_delay_us *** adi,gpo0-rx-delay-us
	0,		//gpo0_tx_delay_us *** adi,gpo0-tx-delay-us
	0,		//gpo1_rx_delay_us *** adi,gpo1-rx-delay-us
	0,		//gpo1_tx_delay_us *** adi,gpo1-tx-delay-us
	0,		//gpo2_rx_delay_us *** adi,gpo2-rx-delay-us
	0,		//gpo2_tx_delay_us *** adi,gpo2-tx-delay-us
	0,		//gpo3_rx_delay_us *** adi,gpo3-rx-delay-us
	0,		//gpo3_tx_delay_us *** adi,gpo3-tx-delay-us
	/* Tx Monitor Control */
	37000,	//low_high_gain_threshold_mdB *** adi,txmon-low-high-thresh
	0,		//low_gain_dB *** adi,txmon-low-gain
	24,		//high_gain_dB *** adi,txmon-high-gain
	0,		//tx_mon_track_en *** adi,txmon-dc-tracking-enable
	0,		//one_shot_mode_en *** adi,txmon-one-shot-mode-enable
	511,	//tx_mon_delay *** adi,txmon-delay
	8192,	//tx_mon_duration *** adi,txmon-duration
	2,		//tx1_mon_front_end_gain *** adi,txmon-1-front-end-gain
	2,		//tx2_mon_front_end_gain *** adi,txmon-2-front-end-gain
	48,		//tx1_mon_lo_cm *** adi,txmon-1-lo-cm
	48,		//tx2_mon_lo_cm *** adi,txmon-2-lo-cm
	/* GPIO definitions */
	-1,		//gpio_resetb *** reset-gpios
	/* MCS Sync */
	-1,		//gpio_sync *** sync-gpios
	-1,		//gpio_cal_sw1 *** cal-sw1-gpios
	-1,		//gpio_cal_sw2 *** cal-sw2-gpios
	/* External LO clocks */
	NULL,	//(*ad9361_rfpll_ext_recalc_rate)()
	NULL,	//(*ad9361_rfpll_ext_round_rate)()
	NULL	//(*ad9361_rfpll_ext_set_rate)()
};

AD9361_RXFIRConfig rx_fir_config = {	// BPF PASSBAND 3/20 fs to 1/4 fs
	3, // rx
	0, // rx_gain
	1, // rx_dec
	{-4, -6, -37, 35, 186, 86, -284, -315,
	 107, 219, -4, 271, 558, -307, -1182, -356,
	 658, 157, 207, 1648, 790, -2525, -2553, 748,
	 865, -476, 3737, 6560, -3583, -14731, -5278, 14819,
	 14819, -5278, -14731, -3583, 6560, 3737, -476, 865,
	 748, -2553, -2525, 790, 1648, 207, 157, 658,
	 -356, -1182, -307, 558, 271, -4, 219, 107,
	 -315, -284, 86, 186, 35, -37, -6, -4,
	 0, 0, 0, 0, 0, 0, 0, 0,
	 0, 0, 0, 0, 0, 0, 0, 0,
	 0, 0, 0, 0, 0, 0, 0, 0,
	 0, 0, 0, 0, 0, 0, 0, 0,
	 0, 0, 0, 0, 0, 0, 0, 0,
	 0, 0, 0, 0, 0, 0, 0, 0,
	 0, 0, 0, 0, 0, 0, 0, 0,
	 0, 0, 0, 0, 0, 0, 0, 0}, // rx_coef[128]
	 64, // rx_coef_size
	 {0, 0, 0, 0, 0, 0}, //rx_path_clks[6]
	 0 // rx_bandwidth
};

AD9361_TXFIRConfig tx_fir_config = {	// BPF PASSBAND 3/20 fs to 1/4 fs
	3, // tx
	-6, // tx_gain
	1, // tx_int
	{-4, -6, -37, 35, 186, 86, -284, -315,
	 107, 219, -4, 271, 558, -307, -1182, -356,
	 658, 157, 207, 1648, 790, -2525, -2553, 748,
	 865, -476, 3737, 6560, -3583, -14731, -5278, 14819,
	 14819, -5278, -14731, -3583, 6560, 3737, -476, 865,
	 748, -2553, -2525, 790, 1648, 207, 157, 658,
	 -356, -1182, -307, 558, 271, -4, 219, 107,
	 -315, -284, 86, 186, 35, -37, -6, -4,
	 0, 0, 0, 0, 0, 0, 0, 0,
	 0, 0, 0, 0, 0, 0, 0, 0,
	 0, 0, 0, 0, 0, 0, 0, 0,
	 0, 0, 0, 0, 0, 0, 0, 0,
	 0, 0, 0, 0, 0, 0, 0, 0,
	 0, 0, 0, 0, 0, 0, 0, 0,
	 0, 0, 0, 0, 0, 0, 0, 0,
	 0, 0, 0, 0, 0, 0, 0, 0}, // tx_coef[128]
	 64, // tx_coef_size
	 {0, 0, 0, 0, 0, 0}, // tx_path_clks[6]
	 0 // tx_bandwidth
};
struct ad9361_rf_phy *ad9361_phy;
#ifdef FMCOMMS5
struct ad9361_rf_phy *ad9361_phy_b;
#endif
/* USER CODE END 0 */

/**
  * @brief  The application entry point.
  * @retval int
  */
int main(void)
{
  /* MCU Configuration--------------------------------------------------------*/

  /* Reset of all peripherals, Initializes the Flash interface and the Systick. */
  HAL_Init();

  /* Configure the system clock */
  SystemClock_Config();

  /* Initialize all configured peripherals */
  MX_GPIO_Init();
  MX_USART1_UART_Init();
  MX_SPI2_Init();
  MX_TIM1_Init();
  MX_ADC1_Init();
  /* USER CODE BEGIN 2 */
  HAL_GPIO_WritePin(RST_FPGA_GPIO_Port, RST_FPGA_Pin, GPIO_PIN_RESET);
  HAL_GPIO_WritePin(GPIOC, GPIO_PIN_13, GPIO_PIN_RESET);
  HAL_Delay(2000);

  Soft_SPI_Init(SOFT_SPI_MODE1);
  printf("System Start\n");
  HAL_GPIO_WritePin(RST_FPGA_GPIO_Port, RST_FPGA_Pin, GPIO_PIN_SET);
  HAL_GPIO_WritePin(GPIOC, GPIO_PIN_13, GPIO_PIN_SET);

  default_init_param.gpio_resetb = -1;
  default_init_param.gpio_sync = -1;
  default_init_param.gpio_cal_sw1 = -1;
  default_init_param.gpio_cal_sw2 = -1;

  default_init_param.dev_sel = ID_AD9363A;

  int ret = ad9361_init(&ad9361_phy, &default_init_param);
  printf("ad9361_init return: %d\n", ret);

  ad9361_set_tx_fir_config(ad9361_phy, tx_fir_config);
  ad9361_set_rx_fir_config(ad9361_phy, rx_fir_config);


  ad9361_set_en_state_machine_mode(ad9361_phy, ENSM_MODE_FDD);

    uint32_t rx_freq, tx_freq;
	ad9361_get_rx_sampling_freq(ad9361_phy, &rx_freq);
	ad9361_get_tx_sampling_freq(ad9361_phy, &tx_freq);
	printf("\n采样频率:\n");
	printf("  RX: %u Hz (%.2f MSPS)\n", rx_freq, rx_freq/1e6);
	printf("  TX: %u Hz (%.2f MSPS)\n", tx_freq, tx_freq/1e6);

	// 4. LO频率
	uint64_t rx_lo, tx_lo;
	ad9361_get_rx_lo_freq(ad9361_phy, &rx_lo);
	ad9361_get_tx_lo_freq(ad9361_phy, &tx_lo);
	printf("\nLO频率:\n");
	printf("  RX: %llu Hz (%.3f GHz)\n", rx_lo, rx_lo/1e9);
	printf("  TX: %llu Hz (%.3f GHz)\n", tx_lo, tx_lo/1e9);



	// uint8_t tx_ctrl = ad9361_spi_read(ad9361_phy->spi, 0x002);
	// tx_ctrl = (tx_ctrl & 0xFC) | 0x01;  // 设置bit[1:0]=01，使能FIR+1x插�??
	// ad9361_spi_write(ad9361_phy->spi, 0x002, tx_ctrl);
	// printf("TX Ctrl after FIR enable: 0x%02X\n", ad9361_spi_read(ad9361_phy->spi, 0x002));

	// uint32_t ensm_state;
	// ad9361_get_en_state_machine_mode(ad9361_phy, &ensm_state);
	// printf("ENSM状�??: %u (FDD=%d)\n", ensm_state, ENSM_MODE_FDD);

	// ad9361_set_en_state_machine_mode(ad9361_phy, ENSM_MODE_TX);

	// ad9361_get_en_state_machine_mode(ad9361_phy, &ensm_state);
	// printf("ENSM状�??: %u (FDD=%d)\n", ensm_state, ENSM_MODE_FDD);

	int32_t tx_gain = 0;  
	ad9361_set_tx_attenuation(ad9361_phy, 0, tx_gain);
	ad9361_set_rx_rf_gain(ad9361_phy, 0, 10);  

	ad9361_set_tx_rf_port_output(ad9361_phy, 0);


	// 3. 读取关键状�??
	uint8_t ensm = ad9361_spi_read(ad9361_phy->spi, 0x017);
	uint8_t tx_ctrl = ad9361_spi_read(ad9361_phy->spi, 0x002);
	uint8_t pll = ad9361_spi_read(ad9361_phy->spi, 0x247);

	printf("\n=== Final Status ===\n");
	printf("ENSM (0x017): 0x%02X (TX_ON=%d)\n", ensm, (ensm>>4)&1);
	printf("TX Ctrl (0x002): 0x%02X\n", tx_ctrl);
	printf("PLL Lock (0x247): 0x%02X (TX_PLL=%d)\n", pll, (pll>>1)&1);



	// ad9361_set_rx_rf_port_input(ad9361_phy, 0);
	// ad9361_set_rx_rf_gain(ad9361_phy, 0, 10); // 10 dB

  /* USER CODE END 2 */

  /* Infinite loop */
  /* USER CODE BEGIN WHILE */
  if (ret != 0)
  {
	  console_print("AD9361 Initialization Failed!\n");
	  while(1);
  }

  while (1)
  {
	  console_get_command(received_cmd);
	  invalid_cmd = 0;
	  for (cmd = 0; cmd < cmd_no; cmd++)
	  {
		  param_no = 0;
		  cmd_type = console_check_commands(received_cmd, cmd_list[cmd].name,
											param, &param_no);
		  if (cmd_type == UNKNOWN_CMD)
		  {
			  invalid_cmd++;
		  }
		  else
		  {
			  cmd_list[cmd].function(param, param_no);
		  }
	  }
	  if(invalid_cmd == cmd_no)
	  {
		  console_print("Invalid command!\n");
	  }
    /* USER CODE END WHILE */

    /* USER CODE BEGIN 3 */
	  
	HAL_GPIO_TogglePin(GPIOC, GPIO_PIN_13);
  }
  /* USER CODE END 3 */
}

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


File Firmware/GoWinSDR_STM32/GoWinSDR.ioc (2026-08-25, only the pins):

Mcu.UserName=STM32F411CEUx
PA0-WKUP.Signal=GPIO_Input
PA1.Signal=GPIO_Input
PA10.Signal=GPIO_Input
PA11.Signal=GPIO_Output
PA12.Signal=GPIO_Input
PA13.Signal=SYS_JTMS-SWDIO
PA14.Signal=SYS_JTCK-SWCLK
PA2.Signal=GPIO_Input
PA3.Signal=GPIO_Input
PA4.Signal=GPIO_Input
PA5.Signal=GPIO_Input
PA6.Signal=GPIO_Input
PA7.Signal=GPIO_Input
PA8.GPIO_Label=RST_FPGA
PA8.Signal=GPIO_Input
PA9.Signal=GPXTI9
PB1.GPIO_Label=FAN
PB1.Signal=GPIO_Output
PB10.Signal=SPI2_SCK
PB14.Signal=SPI2_MISO
PB15.Signal=SPI2_MOSI
PB3.Signal=USART1_RX
PB6.Signal=USART1_TX
PC13-ANTI_TAMP.Signal=GPIO_Output

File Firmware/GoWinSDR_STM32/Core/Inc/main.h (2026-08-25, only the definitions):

#define FAN_Pin GPIO_PIN_1
#define FAN_GPIO_Port GPIOB
#define RST_FPGA_Pin GPIO_PIN_8
#define RST_FPGA_GPIO_Port GPIOA

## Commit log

2026-07-24 添加v2版本描述
2026-07-25 实现ARP请求
    [device.cfg, ila_sdr_core0.csv]
2026-07-27 添加外壳文件
    [base.SLDPRT, base.STL, base2.STL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]
2026-08-19 发射路径基本完成
    [base.SLDPRT, base3.STL, ila_sdr_core0.csv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]
2026-08-25 修复QPSK相位问题
    [ila_sdr_core0.csv]
2026-08-26 基本修复gardner环
    [ila_sdr_core0.csv]
2026-08-26 短消息回环测试完成
    [ila_sdr_core0.csv]
2026-08-26 修复大文件传输问题
2026-08-26 修改LED显示逻辑，只在收发包时亮起
2026-08-27 添加流控和DDR缓冲区
    [ila_sdr_core0.csv, ila_sdr_core1.csv]
2026-08-28 上位机实现基本流控
    [ila_sdr_core0.csv, ila_sdr_core1.csv, ila_sdr_core2.csv]

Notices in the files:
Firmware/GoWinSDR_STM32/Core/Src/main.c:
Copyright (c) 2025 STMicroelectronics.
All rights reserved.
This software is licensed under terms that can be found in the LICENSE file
